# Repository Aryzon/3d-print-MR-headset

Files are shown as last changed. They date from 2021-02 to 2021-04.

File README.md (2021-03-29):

# 3d-print-MR-headset
Here you will find the 3D files which contain the Aryzon 3D printable MR headset. This headset uses your iOS or Android phone to show content in true volumetric 3D, similar to other expensive headsets like the Microsoft HoloLens. It is developed by us at Aryzon and works with our AR Studio app so you can easily visualize models from Sketchfab, Google Poly or your own 3D models.

## Remix the design
We have open sourced the design of the headset and anyone is welcome to change it or make recommendations to improve it.

## The parts
There are some parts that cannot be printed, like the visor, mirror, lenses, headband and (new in V1.1) elastic band. You can order these parts here: https://www.aryzon.com/3dprint.

Tip: If you do not have the elastic band contact us to get it or use a hair elastic.

## Print instructions
On FDM printers place the flat front-most surface on the print bed. Print the parts at 100% of their size. We have had great results with a layer height of 0.2 mm. A smaller layer height is possible but will make your print a lot slower without much benefit since this is quite a large print.

1) Set your printer to the appropriate settings for the filament used, we tested PLA and ABS.
2) A layer height of 0.2 mm will provide great results, smaller is not necessary.
3) Use an infill percentage of 10-20%, higher will cause a heavier headset, meaning less comfortable.
4) Use a brim layer if curling up from the printbed is an issue.
5) Turn on support. If you are confident your printer can print up to a 45 degree overhang angle you can tweak the support angle / overhang threshold so it looks like this. (Overhang Threshold = 79 in XYZPrint):

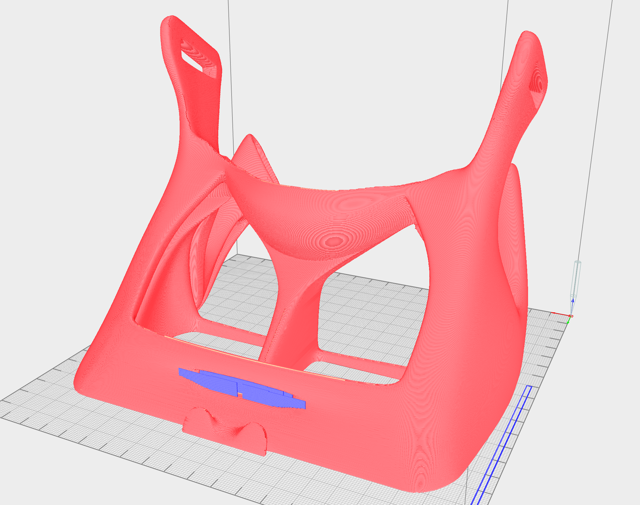
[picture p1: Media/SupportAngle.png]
<br>

Tip: Lowering the print speed helps to reduce the chances of many issues.

### Supported printers
Any 3D printer with a print bed of at least 190x155 mm that can print 150 mm high is supported.
If really necessary you can cut the model in half, print both halves and glue them together. A heated print bed is advised since curling can more quickly become an issue on larger parts.

## Assembly instructions
We made a video to help you quickly assemble the headset. You can find the instructions at https://www.aryzon.com/3dprint.

## Supported phones
There are two basic checks to see if your phone is supported:
1) Your phone must not be larger than 166 mm in length (that's quite big)
2) Your phone will need to be able to do room-scale tracking. You can see how well your phone does this by trying out the Aryzon AR Studio app.

## Unity3D Developers
All our headsets including the 3D printed one work with our Unity SDK, any Unity dev can easily create their own app for the headset. (You can even build HoloLens applications using MRTK 2+ for your phone!) More details here: https://www.aryzon.com/creators.

## Idea behind the design
Our focus has been to make this headset easy to print and assemble so it can be printed by the average 3D printing enthusiast. The design therefore exists of only 2 parts to print and requires only little support material.

# License
All files in this repository are licensed under Creative Commons Attribution 4.0 International (CC BY 4.0). See file LICENSE for more details.

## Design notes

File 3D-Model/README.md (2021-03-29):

Version History
-
V1.1
* A new way to secure the phone holder to the main body. 3 mm elastic cord is to be looped through the holes in the phone holder and secured to the main body at the top.
* Added sockets for the foam pieces to keep them better in place.
* Improved system to keep the mirror and lenses in place.
* No more support material required for the phone holder.
* Less support material required for the main body.

V1.0
* First release

Base model
-
Use the base model if you want to edit the model.

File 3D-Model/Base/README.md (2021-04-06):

Edit the Base model
-
If you want to edit a model it is easiest to use the base models. These are the models used before they are subdivided to generate a smooth model so they have way less vertices to work with.

Import to Gravity Sketch
-
If you have a VR headset you can use Gravity Sketch to modify the base models:
1) Import the models to your Landingpad.
2) Go into Gravity Sketch and import the models to your sketch. Set dimensions to millimetres and rotate to make it upright.
3) Go into edit mode of the model and select 'Convert to Subdivision Object'.
4) Optional: Delete all vertices on one half of the model and select 'Mirror'. It should automatically connect the center vertices.

Export Gravity Sketch
-
To use the model that was edited in Gravity Sketch you will need specific export settings:

Choose 'Export' and go to 'Advanced Settings' then set Sided Normals to 'Welded'.
Set Subd to 'Base' if you want to further edit this model in another program like Blender.
Set Subd to 'Smooth' if you want to export a printable model. Make sure the front surface is still flat and set the subdivision level on the model to max.

From Base to Printable model
-
1) Import the base model to Blender
2) Add a 'Subdivision Surface' modifier and set the viewport level to 3.
3) (Only for the main body) add a cube to the scene with settings:
	Location:
	x: -70 y: 68, z: -66
	Rotation:
	x: 0 y: 0 z: 45
	Scale
	x: 7.0 y: 1.5 z: 1.4
4) (Only for the main body) add a 'Boolean' modifier on the Main body, set it to Union and choose the cube from step 3 as the object.
5) With another 'Boolean' modifer set to 'Difference' slice a thin piece off the front of the main body and the phone holder to make it flat. Use a large enough cube for example as the object. 
5) Select the model you want to export. Choose File -> Export -> STL. Set it to export only the selected object and choose the up axis of your printer, (often Y-up).

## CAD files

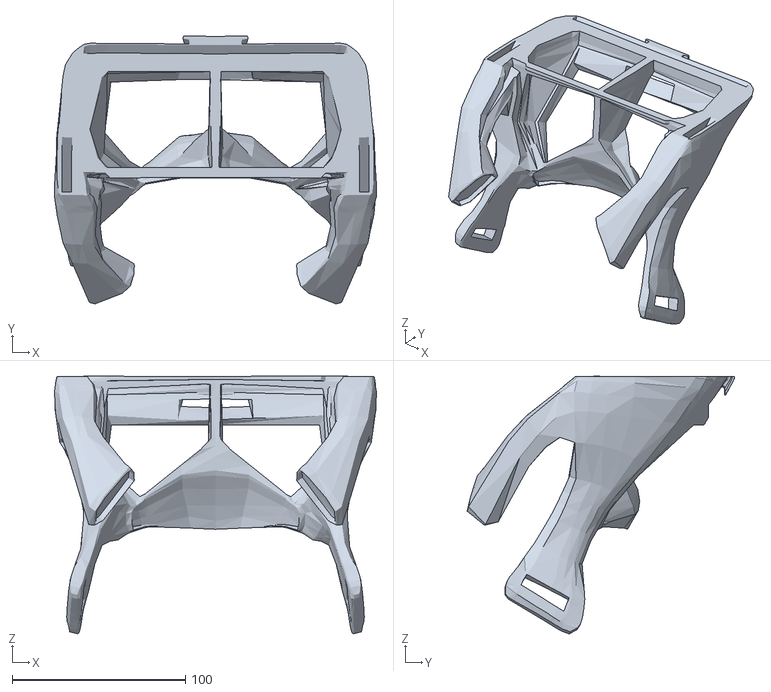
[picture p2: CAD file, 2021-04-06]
3D-Model/Base/Headset_Main_Base.obj
185.8 x 154.5 x 148.8

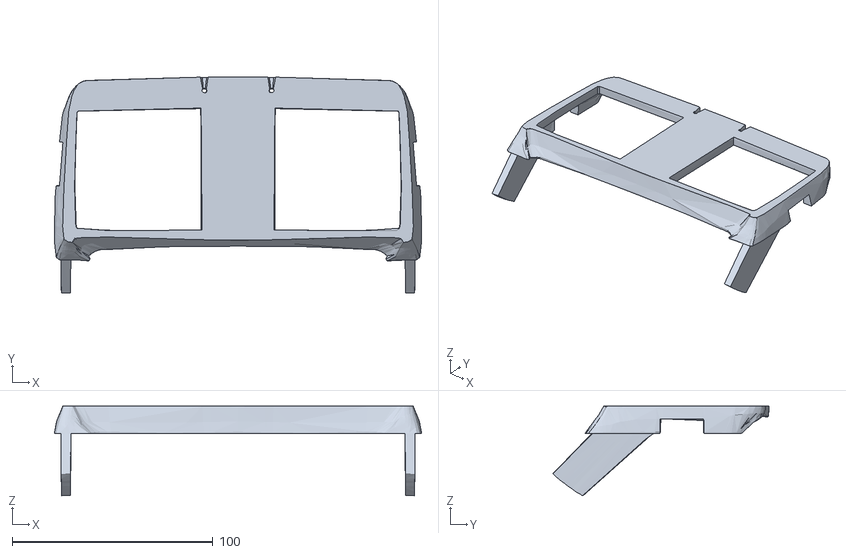
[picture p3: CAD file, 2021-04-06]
3D-Model/Base/Headset_PhoneHolder_Front.obj
183.0 x 107.8 x 44.7

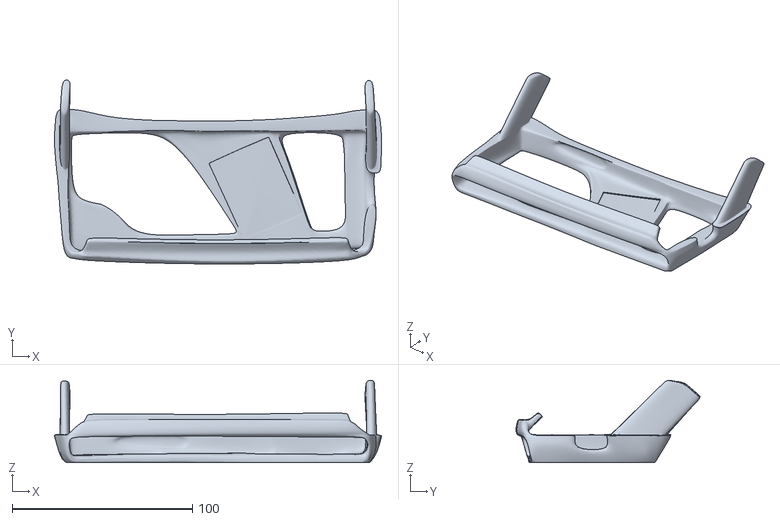
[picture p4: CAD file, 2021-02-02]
3D-Model/Headset_PhoneHolder.stl
181.2 x 101.9 x 45.6

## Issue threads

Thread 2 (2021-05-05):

V1.1 assemble instruction appear to be missing

leoshmu, 2021-05-05:
Do you have instructions for the v1.1 elastic band? The current design seems to be one iteration ahead of the youtube instruction video

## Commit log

2021-02-02 Changed to STL
    [Headset_PhoneHolder.stl]
2021-03-25 Design changes
    [Headset_PhoneHolder_legacy.stl]
2021-03-26 Small tweak to reduce footprint
2021-03-26 Change next verion model name to experimental
    [Headset_PhoneHolder.stl]
2021-03-29 Version 1.1
    [Headset_Main_Base.stl, Headset_Phone_Holder_Base.stl]
2021-04-06 Rotated and flattened models
    [Headset_Main_Base.obj, Headset_Main_Base.stl, Headset_PhoneHolder_Front.obj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]
